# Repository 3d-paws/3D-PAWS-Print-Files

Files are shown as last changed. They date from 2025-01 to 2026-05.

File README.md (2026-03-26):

# 3DPAWS Weather Station 3D Printing Files

## Description
Repository containing .stl and .3mf files for 3D printing parts for the 3DPAWS (3D-Printed Automatic Weather Station) project. Create your own low-cost, reliable surface weather station.

## File Types
- `.stl`: Universal 3D printing file format
- `.3mf`: Optimized for Bambu Labs printers

## File Naming and Part Identification
The print files in this repository are organized by component and follow a consistent naming convention. However, some file names may not be immediately intuitive when viewed independently. To more easily identify the correct parts:
- Refer to the parts list at the beginning of the corresponding section in the 3D-PAWS manual
- Match file names in this repository to the listed components
- Use the manual diagrams to confirm part identification and placement
- Preview the .stl files in each folder to visualize the parts (files are shown without supports)

The repository is structured by subsystem (e.g., rain gauge, wind vane, radiation shield), so using the manual alongside these files will significantly improve navigation and part selection.

## Downloading Options

### 1. Individual Files
Browse the repository and download specific files as needed.

### 2. Complete Package
Download the entire repository as a zip file using the "Code" button on the GitHub interface.

### 3. Specific Folders
To download individual folders, use: 
https://download-directory.github.io/

Simply copy the URL of the desired folder from this repository and paste it into the tool.

## Printing Recommendations

### Filament Choice
We recommend using a high-quality ASA filament for optimal results. ASA is an excellent alternative to ABS, offering improved weather resistance, UV resistance, and excellent mechanical properties, making it ideal for outdoor applications like weather stations.

Recommended filament: 
- PolyLite™ ASA by Polymaker (https://us.polymaker.com/products/polylite-asa)
- Overture (https://overture3d.com/collections/all-filaments/products/overture-asa-filament-1-75mm)

### Print Settings
- **Nozzle Temperature:** 240°C - 260°C
- **Bed Temperature:** 75°C - 95°C
- **Print Speed:** 30mm/s - 50mm/s
- **Cooling Fan:** Off
- **Infill:** 99-100% (to improve strength and reduce water absorption)

### Additional Tips
1. Use an enclosure to maintain a stable printing environment, ideally with an ambient temperature between 35°C - 45°C.
2. Print on a textured PEI sheet or use polyimide tape for better adhesion.
3. Adding a 5mm brim can significantly improve bed adhesion.
4. For large or thin models, printing in an enclosure or heated chamber is highly recommended.

## About 3DPAWS
The 3DPAWS initiative increases meteorological observations by enabling local construction of weather stations. Using 3D-printed parts makes weather monitoring more accessible and cost-effective for developing countries and rural communities. Refer to the 3DPAWS manual for more information: https://3dpaws.comet.ucar.edu/

## Contributing
We encourage exploration of the files and contributions to the 3DPAWS network. Open an issue or submit a pull request with any questions or improvements.

Happy printing and weather monitoring! 🌦️🖨️

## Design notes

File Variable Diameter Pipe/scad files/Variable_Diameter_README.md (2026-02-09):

# PVC Pipe Component Sizing

These OpenSCAD (.scad) models are part of the 3D-PAWS Print Files repository and are designed for use with PVC pipe–based assemblies.

Because PVC pipe outer diameters vary by region, schedule, and manufacturer, these models are parameterized so they can be easily adjusted to fit locally available pipe.

## How Pipe Sizing Works

Each .scad file defines pipe dimensions using a top-level variable rather than fixed geometry.
Before rendering or exporting a model, you must update this variable to match the measured outer diameter of your PVC pipe.

## Pipe Radius Variables

Depending on the file, you may see one or more of the following variables defined near the top of the file:

- SPR — Small Pipe Radius (mm)
- LPR — Large Pipe Radius (mm)
- PR  — Pipe Radius (mm)

These values represent the radius of the pipe, not the nominal pipe size.

Example:

    PR = 16.7;  // Pipe radius in mm

This corresponds to a pipe with an outer diameter of approximately 33.4 mm.

## Adjusting a Model for Your Local Pipe

1. Measure the outer diameter of your PVC pipe using calipers.
2. Divide the measurement by two to get the radius.
3. Open the .scad file in OpenSCAD.
4. Modify the appropriate variable (SPR, LPR, or PR) at the top of the file.
5. Render and export the STL.

Always use measured dimensions rather than relying on nominal pipe sizes.

## Notes on Fit and Tolerances

- Nominal PVC sizes (e.g., “1 inch”, “1/2 inch”) do not reflect actual dimensions.
- Print material, printer calibration, and slicer settings may affect fit.
- Some parts include multiple pipe interfaces and will define both SPR and LPR.

## Design Rationale

This approach allows the same OpenSCAD models to be reused across different regions and supply chains without duplicating files.
Adjusting a single variable ensures the geometry adapts correctly to your local PVC pipe dimensions.

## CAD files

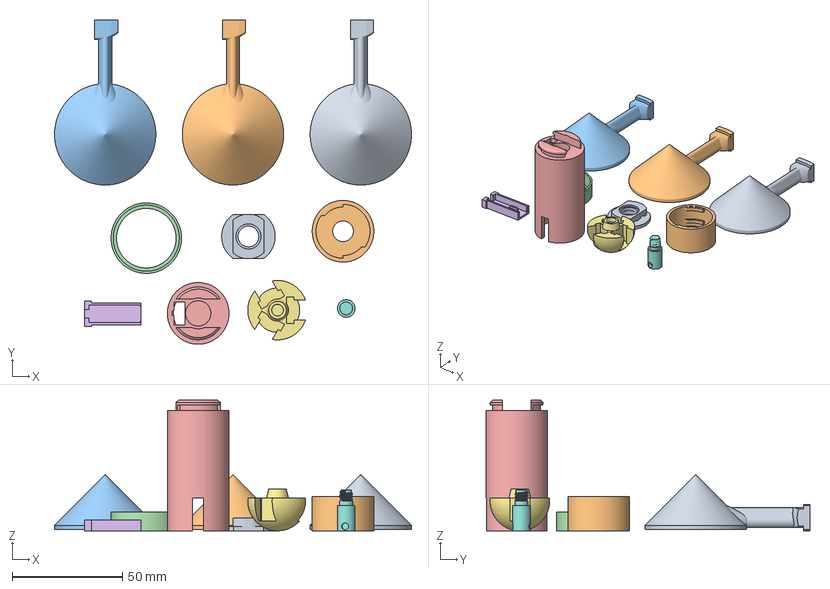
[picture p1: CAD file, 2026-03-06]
Anemometer/full anemometer.3mf
162.0 x 147.2 x 59.3 mm
cup.stl x 3
skirt.stl
base.stl
sensor holder.stl
threaded hub tapered post.stl
threaded shaft WS2.stl
bearing holder.stl
body.stl

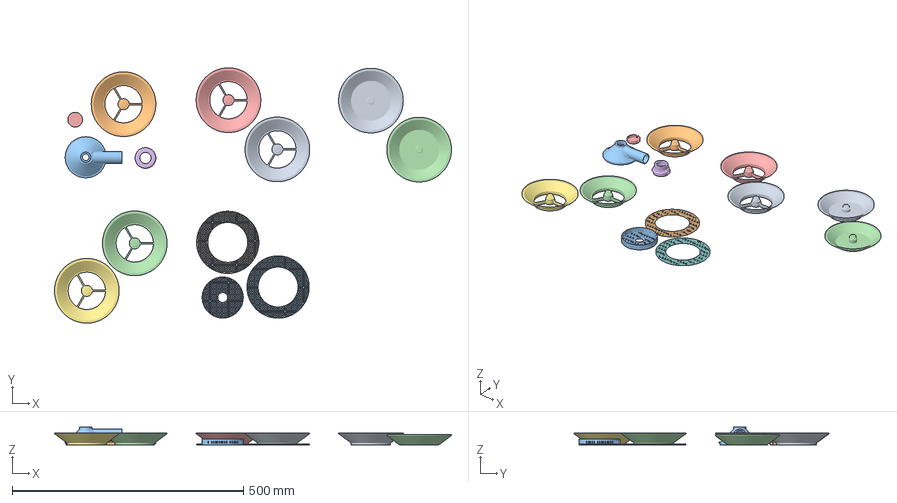
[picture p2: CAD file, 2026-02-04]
Radiation Shield and Wiring/RS Assembly/rs full.3mf
859.3 x 552.6 x 38.0 mm
closed leaf no shaft.stl
open leaf no shaft.stl x 5
conical base no shaft.stl
top leaf no shaft.stl
locking threads.stl
screen ring max.stl x 2
center screen vented wall.stl
base cover.stl

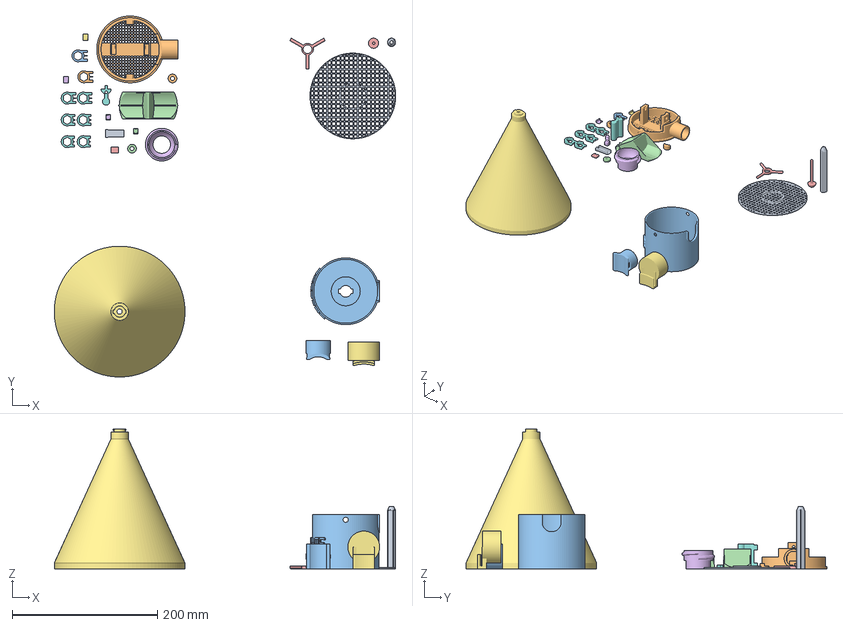
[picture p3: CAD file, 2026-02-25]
Rain Gauge/full rain gauge.3mf
470.1 x 497.0 x 192.1 mm
vertical screen.stl
base.stl
3D-PAWS cover.stl
bucket.stl
vertical screen cap.stl
locking threads.stl
RG upper cover clamp.stl
counter balance.stl
Horizontal screen.stl
rivet filing guide.stl
RG lower cover clamp.stl
fastner.stl x 2
vertical screen support.stl
fixed funnel.stl
stops.stl
sensor holder.stl
6.5 stop.stl x 2
rivet trimming guide.stl
sensor resistor spacer.stl
bucket retainer clip.stl x 2

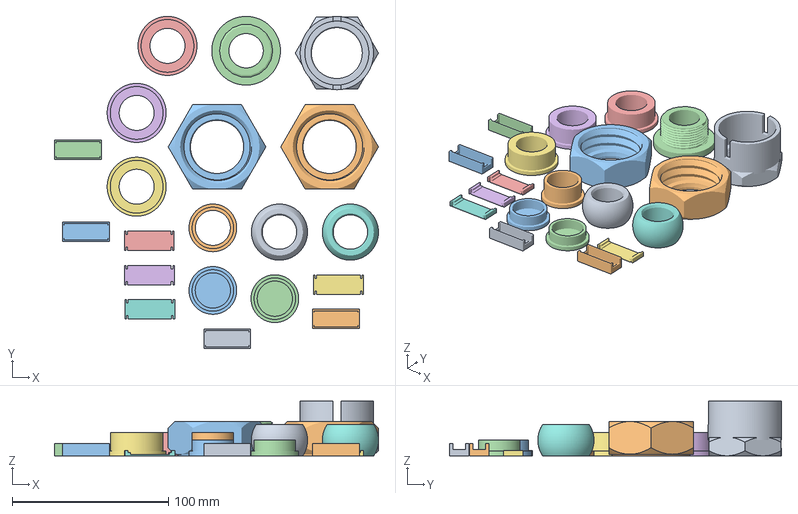
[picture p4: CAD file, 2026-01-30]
Station Assembly/Full Station.3mf
207.6 x 212.8 x 35.0 mm
box adapter female.stl
levelling joint lock nut.stl x 2
box adapter male.stl
1in fitting to 3-4 cpvc adapter.stl x 3
levelling joint olive.stl x 2
1in pipe to 3-4 cpvc.stl
1 in end cap.stl x 2
small M5 connector lid.stl x 4
small M5 connector holder.stl x 4

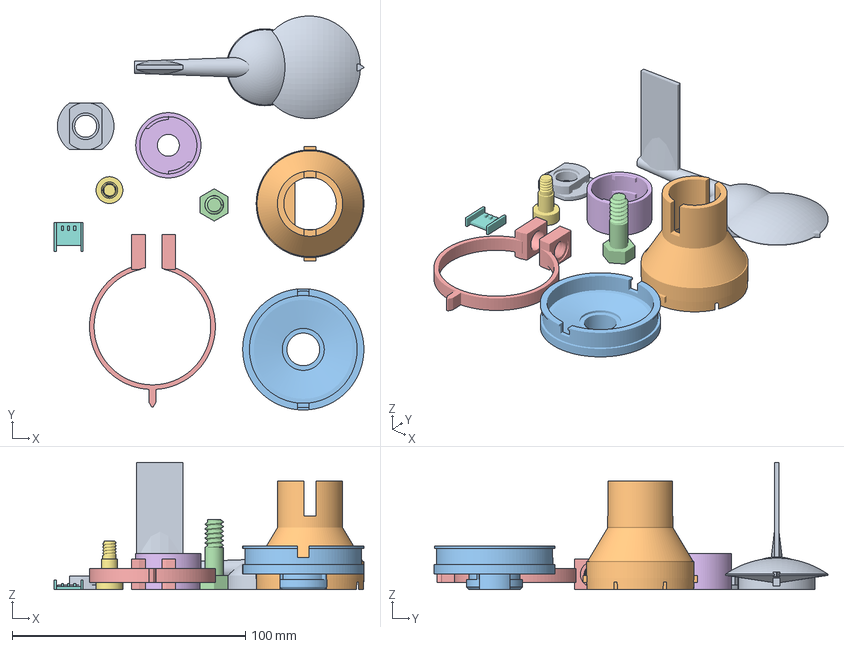
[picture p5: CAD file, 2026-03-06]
Wind Vane/full vane.3mf
132.9 x 169.0 x 54.5 mm
rotor.stl
base.stl
flat cover.stl
clamp bolt.stl
pointer.stl
body.stl
threaded shaft WD.stl
glue cover.stl
bearing holder.stl

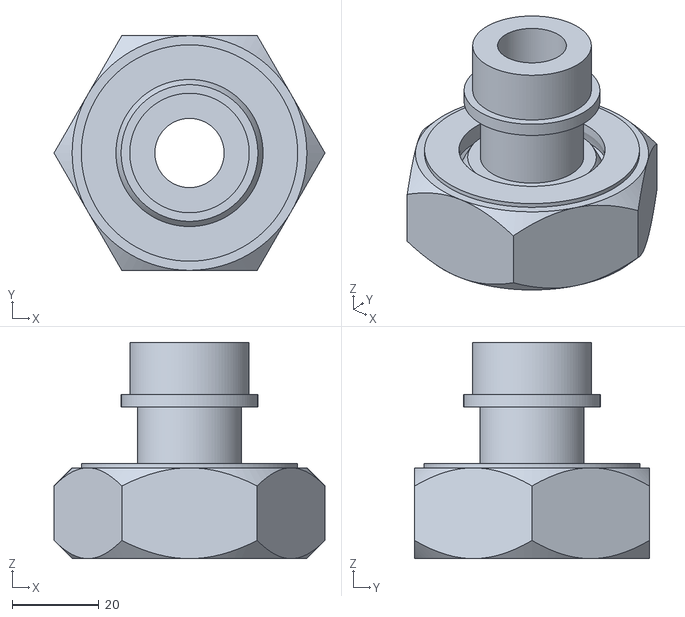
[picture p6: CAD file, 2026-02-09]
Variable Diameter Pipe/32mm/full swivel for RS.stl
62.6 x 54.2 x 50.0

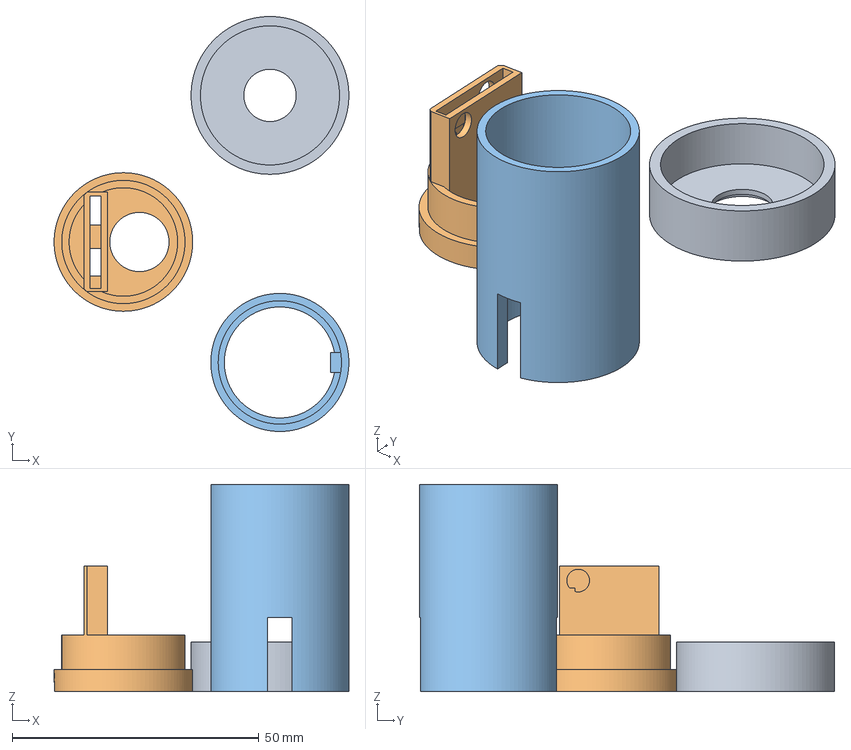
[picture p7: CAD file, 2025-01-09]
Light Sensor/full light sensor.3mf
59.8 x 84.1 x 42.0 mm
cover.stl
sensor holder.stl
body.stl

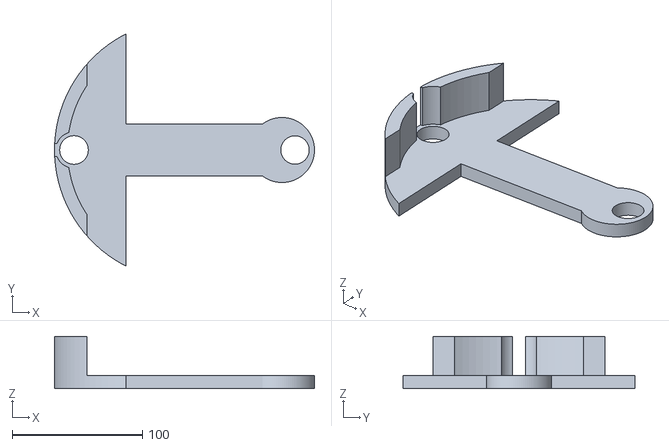
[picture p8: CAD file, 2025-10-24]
Soil Moisture and Temperature/Installation Tool/full foot.stl
200.0 x 178.5 x 40.0

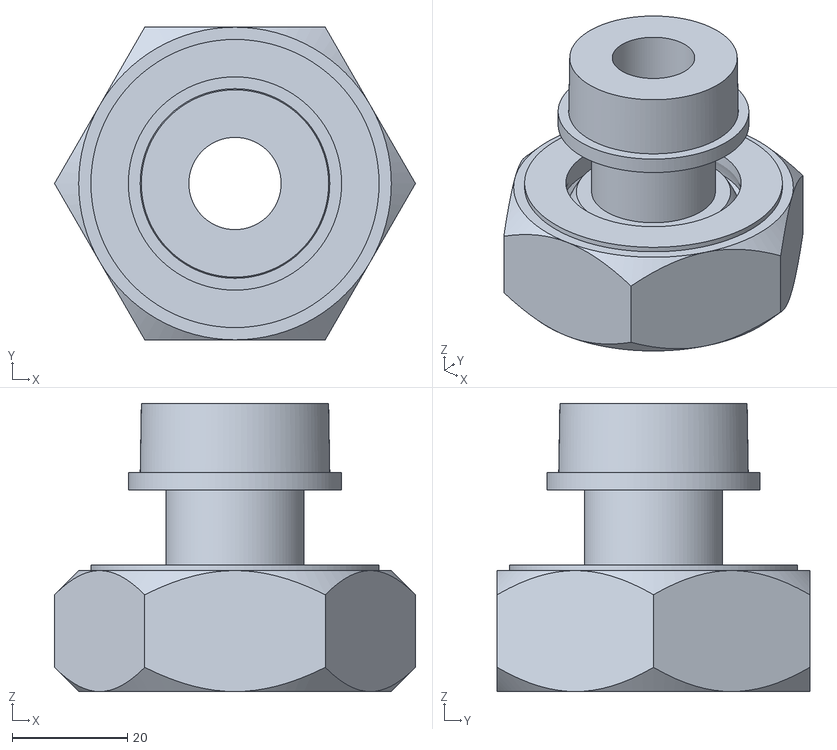
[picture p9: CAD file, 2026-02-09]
Variable Diameter Pipe/32mm/full swivel for rain.stl
62.6 x 54.2 x 50.0

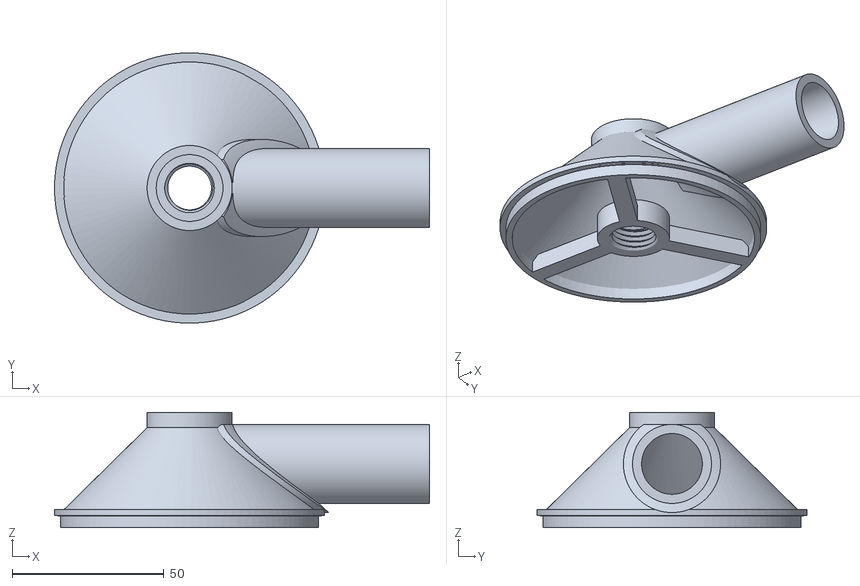
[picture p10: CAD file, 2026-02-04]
Air Quality/conical base no shaft.stl
123.5 x 89.0 x 38.0

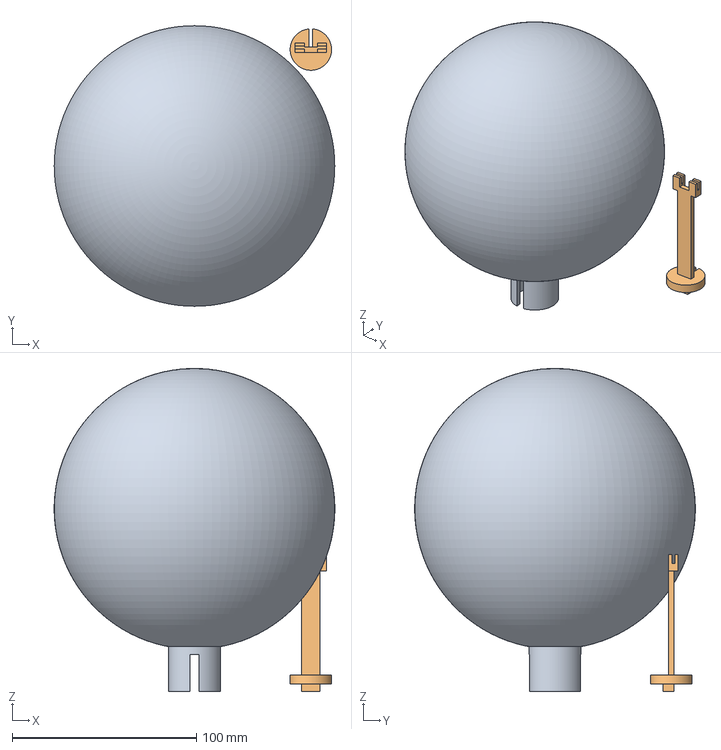
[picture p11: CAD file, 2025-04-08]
Black Globe/6in black globe.3mf
152.3 x 152.3 x 175.4 mm
6in black globe.stl
6in globe sensor holder.stl

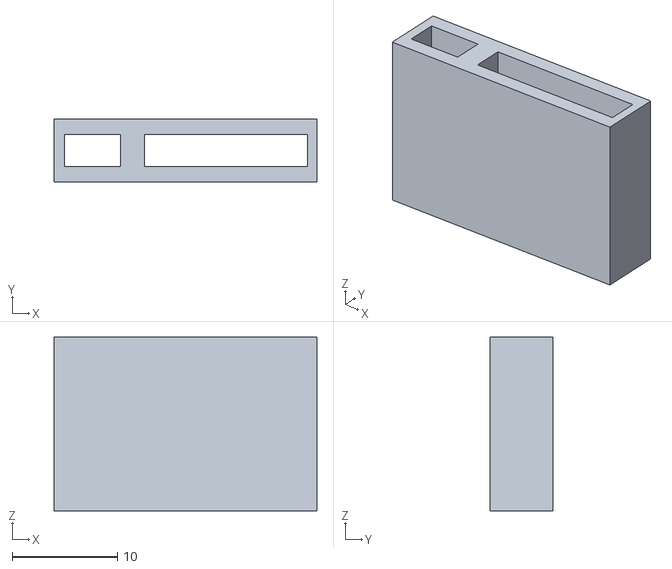
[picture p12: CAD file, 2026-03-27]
Data Logger/LoRa radio connector for receiver.stl
25.0 x 6.00 x 16.5

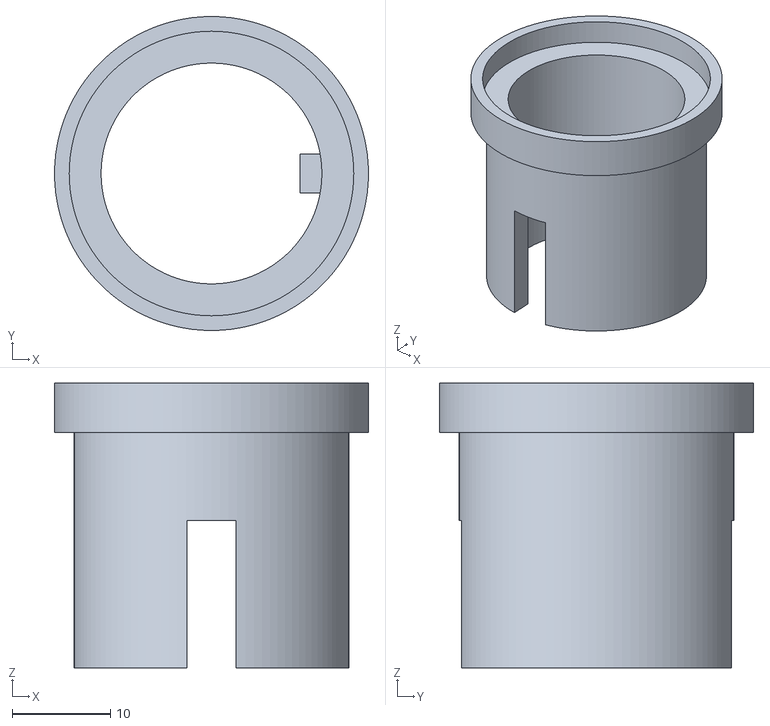
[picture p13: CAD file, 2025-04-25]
Light Sensor/dfrobot body.stl
32.0 x 32.0 x 29.0

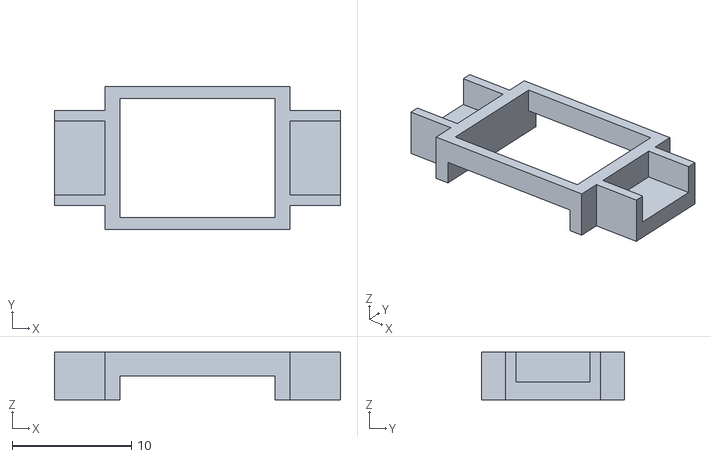
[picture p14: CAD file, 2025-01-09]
Radiation Shield and Wiring/Wiring/glue cover.stl
24.0 x 12.0 x 4.00

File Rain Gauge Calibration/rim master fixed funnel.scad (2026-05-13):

// =============================================================
// 3D-PAWS Rain Gauge - Calibrated Rim
// =============================================================
//
// PURPOSE:
//   This file generates the calibrated rim for the tipping bucket
//   rain gauge. The rim diameter is calculated during the calibration
//   process to ensure the gauge tips at exactly 0.2mm of rain.
//
// HOW TO USE THIS FILE:
//   1. Complete the calibration procedure as described in the manual.
//   2. Use the "Rim Radius Calculation" spreadsheet to determine
//      the correct radius value from your calibration data.
//   3. Update ONLY the 'radius' variable below with your calculated value.
//   4. Export as STL: File > Export > Export as STL.
//
// *** DO NOT change any other values in this file. ***
// =============================================================


// --- SMOOTHNESS SETTING (do not change) ---
$fn = 100;

// --- CALIBRATED RADIUS (mm) ---
// *** UPDATE THIS VALUE ONLY ***
// Replace the number below with the radius calculated from your
// calibration spreadsheet (e.g. the manual example gives 99.19852).
// Copy the value to at least 2 decimal places for accuracy.
radius = 97.91923434;


// --- RIM GEOMETRY (DO NOT CHANGE BELOW THIS LINE) ---

// Outer funnel cone: tapers outward from the base to the calibrated radius
translate([0, 0, 7.9])
difference() {
    cylinder(80, 88, radius + 2);          // outer wall of funnel cone
    translate([0, 0, -1]) cylinder(85, 86, radius); // inner cutout
}

// Base rim ring: the fixed-diameter collar that sits on the gauge body
difference() {
    cylinder(8, 88, 88);                   // outer rim cylinder
    translate([0, 0, -5]) cylinder(120, 86, 86); // inner cutout
}

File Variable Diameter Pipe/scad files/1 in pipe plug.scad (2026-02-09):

// pvc pipe plug

$fn=100;

PR=13.4; //enter inner pvc pipe radius here (for 1" pvc pipe, PR=13.2; for 32mm 13.4; for standard 1" PVC fitting, PR=16.90)

difference(){
    cylinder(10,PR,PR-0.25); 
    cylinder(30,PR-2,PR-2);
    }

cylinder(3,PR+2,PR+2); 

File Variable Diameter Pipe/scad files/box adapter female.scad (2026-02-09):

// modular box adapter female with threads

$fn=100;

PR=21.25; // enter pvc fitting outer radius here (for standard 1" PVC 4 way tee, PR=20.50)

//threads
scale([1.1,1.1,1])import("box to pipe adaptor nut2.stl");

//clamp ring
translate([0,0,10]) difference() {
    cylinder(25,PR+3,PR+3);
    translate([0,0,-1]) cylinder(55,PR,PR);
    translate([-2.5,-40,10]) cube([5,80,25]);
    }
//reenforcement 
translate ([0,0,10]) difference() {
    cylinder(5,PR+3,PR+3);
    translate([0,0,-1])cylinder(55,PR,PR);
    }

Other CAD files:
Rain Gauge Calibration/calibration parts.3mf
Rain Gauge/Funnel/vertical screen.stl
Snow Gauge/Snow_Gauge.3mf
Soil Moisture and Temperature/2 cable inlet plug.stl
Variable Diameter Pipe/scad files/cable inlet plug.scad
Air Quality/AQ center screen.stl
Air Quality/AQ screen ring.stl
Air Quality/air quality 2nd leaf.stl
Air Quality/air quality closed leaf.stl
Air Quality/air quality open leaf.stl
Air Quality/air quality sensor cover.stl
Air Quality/air quality sensor seat.stl
Air Quality/air quality sensor.3mf
Air Quality/air quality top leaf.stl
Anemometer/base.stl
Anemometer/bearing holder.stl
Anemometer/body.stl
Anemometer/cup.stl
Anemometer/sensor holder.stl
Anemometer/skirt.stl
Anemometer/threaded hub.stl
Anemometer/threaded shaft WS.stl
Black Globe/3in black globe.3mf
Black Globe/3in black globe.stl
Black Globe/3in globe sensor holder.stl
Black Globe/6in black globe.stl
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

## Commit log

2025-01-09 Add files via upload
    Adding Anemometer .stl files
    [anemometer lower.3mf, anemometer rotor.3mf, base.stl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]
2025-01-09 Changing Design folder name to Anemometer
    [anemometer lower.3mf, anemometer rotor.3mf, base.stl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]
2025-01-09 Wind Vane .stl files
    [alignment cap.stl, alignment clip.stl, base.stl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]
2025-10-24 Adding Soil Moisture and Temp files + install tool
    [PM WCS 3 insert seat4.stl, actuator.stl, full foot.stl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]
2026-01-30 Delete Anemometer/body with bearing holder.stl
    Duplicate
    [body with bearing holder.stl]
2026-01-30 Rename black globe.stl to 3in black globe.stl
    [3in black globe.stl]
2026-01-30 Rename globe sensor holder.stl to 3in globe sensor holder.stl
    [3in globe sensor holder.stl]
2026-02-17 updating wind vane base
    [base.stl, calibration parts.3mf]
2026-02-25 updated rg funnel to 100% infill
    [full rain gauge.3mf]
2026-02-25 added 3d-printed tools and updated wind vane threaded shaft
    [alignment clip.stl, direction setter.stl, loom.stl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]
2026-02-27 adding standoffs for the tripod and scad file
    [stand off 17_16_Tt_P.stl, stand off 17_20_Tt_F.stl, stand off 19_16_Tb_P.stl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]
2026-03-02 Changing the data logger rack to accomodate new battery
    [box rack LH.stl, rack for box and battery RH.stl, stream leveling tool.stl]
2026-03-05 adjusting rotation of the universal clamp
    [stand off 2in post with strap.stl, voltaic solar.3mf]
2026-03-05 adjusted the bearing holder
    [bearing holder.stl]
2026-03-06 adjusted the .3mf
    [full anemometer.3mf]
2026-03-06 updated .3mf
    [full vane.3mf]
2026-03-06 added pvc end caps to solar
    [1 in end cap.stl, rain cover.stl, voltaic solar.3mf]
2026-03-10 adding wind vane magnet press tool
    [wind vane magnet press tool.stl]
2026-03-26 adding mkr antenna clip
    [antenna clip MKR.stl, antenna clip argon.stl, antenna clip boron.stl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]
2026-03-27 Adding LoRa radio connector for receiver
    [LoRa radio connector for receiver.stl]
2026-05-13 Added instructions to the Rim Master Funnel.stl file
    [rim master fixed funnel.scad]
2026-05-20 adding box adapter female_variable_pvc.stl
2026-05-21 adding standoff to scad files
2026-07-10 added nylon threaded shaft for anemometer and wind vanes
2026-07-21 Adding Rain Gauge Calibration Drip Controller
2026-09-10 updated flat cover for new nylon threads
2026-10-05 new wind vane sensor base
2026-10-26 updated swivels .stl for 1in pipe
2026-10-28 adding rapid deployment cable parts
